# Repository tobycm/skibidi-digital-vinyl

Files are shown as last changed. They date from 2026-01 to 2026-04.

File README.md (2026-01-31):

# skibidi-digital-vinyl

a really cool vinyl emulator with digital tech

## Idea

Discs are made out of CH32V003 mcu, BY25Q32 flash, acts as a storage for audio file. Powered through pogo pins when placed in the player.

The player is powered with a RP2040 mcu, PTC PT8211-S DAC, and PAM8403 amplifier. USB powered, maybe battery powered in the future.

Maybe add a spinning motor in the future for extra effect.

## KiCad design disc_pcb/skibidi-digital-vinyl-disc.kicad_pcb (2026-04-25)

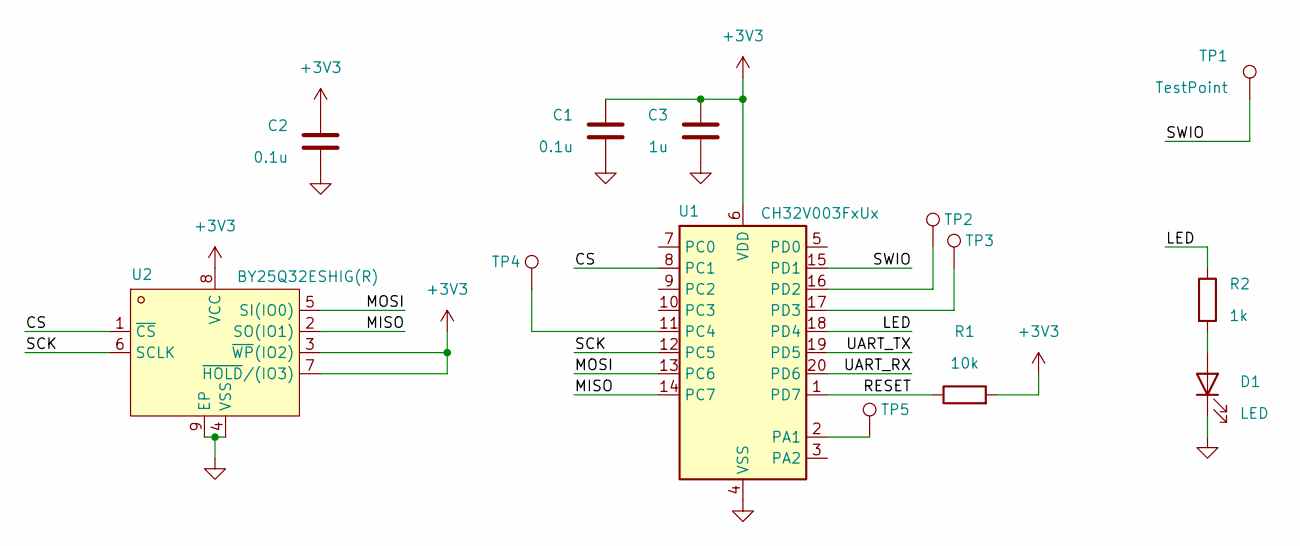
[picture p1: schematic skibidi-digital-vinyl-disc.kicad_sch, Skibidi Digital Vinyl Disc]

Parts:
C1, C2: 0.1u; C_0402_1005Metric; LCSC Part # C1525
C3: 1u; C_0402_1005Metric; LCSC Part # C52923
D1: LED; LED_0603_1608Metric; LCSC Part # C22371297
R1: 10k; R_0603_1608Metric; LCSC Part # C25804
R2: 1k; R_0603_1608Metric; LCSC Part # C21190
TP1, TP2, TP3, TP4, TP5: TestPoint; TestPoint_Pad_D1.0mm
U1: CH32V003FxUx; QFN-20-1EP_3x3mm_P0.4mm_EP1.65x1.65mm
U2: BY25Q32ESHIG(R); DFN-8_L4.0-W3.0-P0.80-TL-EP_GT5YL24A1Y520; LCSC Part C50176326

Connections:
+3V3: C1.1, C2.1, C3.1, R1.2, U1.6 (VDD), U2.3 (~WP(IO2)), U2.7 (~HOLD/(IO3)), U2.8 (VCC)
/CS: U1.8 (PC1), U2.1 (~CS)
/LED: R2.1, U1.18 (PD4)
/MISO: U1.14 (PC7), U2.2 (SO(IO1))
/MOSI: U1.13 (PC6), U2.5 (SI(IO0))
/RESET: R1.1, U1.1 (PD7)
/SCK: U1.12 (PC5), U2.6 (SCLK)
/SWIO: TP1.1, U1.15 (PD1); also elsewhere on the board
/UART_RX: U1.20 (PD6)
/UART_TX: U1.19 (PD5)
GND: C1.2, C2.2, C3.2, D1.1 (K), U1.4 (VSS), U1.21 (VSS), U2.4 (VSS), U2.9 (EP), U2.10 (EP)
unnamed: D1.2 (A), R2.2
unnamed: TP5.1, U1.2 (PA1)
unnamed: TP4.1, U1.11 (PC4)
unnamed: TP2.1, U1.16 (PD2)
unnamed: TP3.1, U1.17 (PD3)

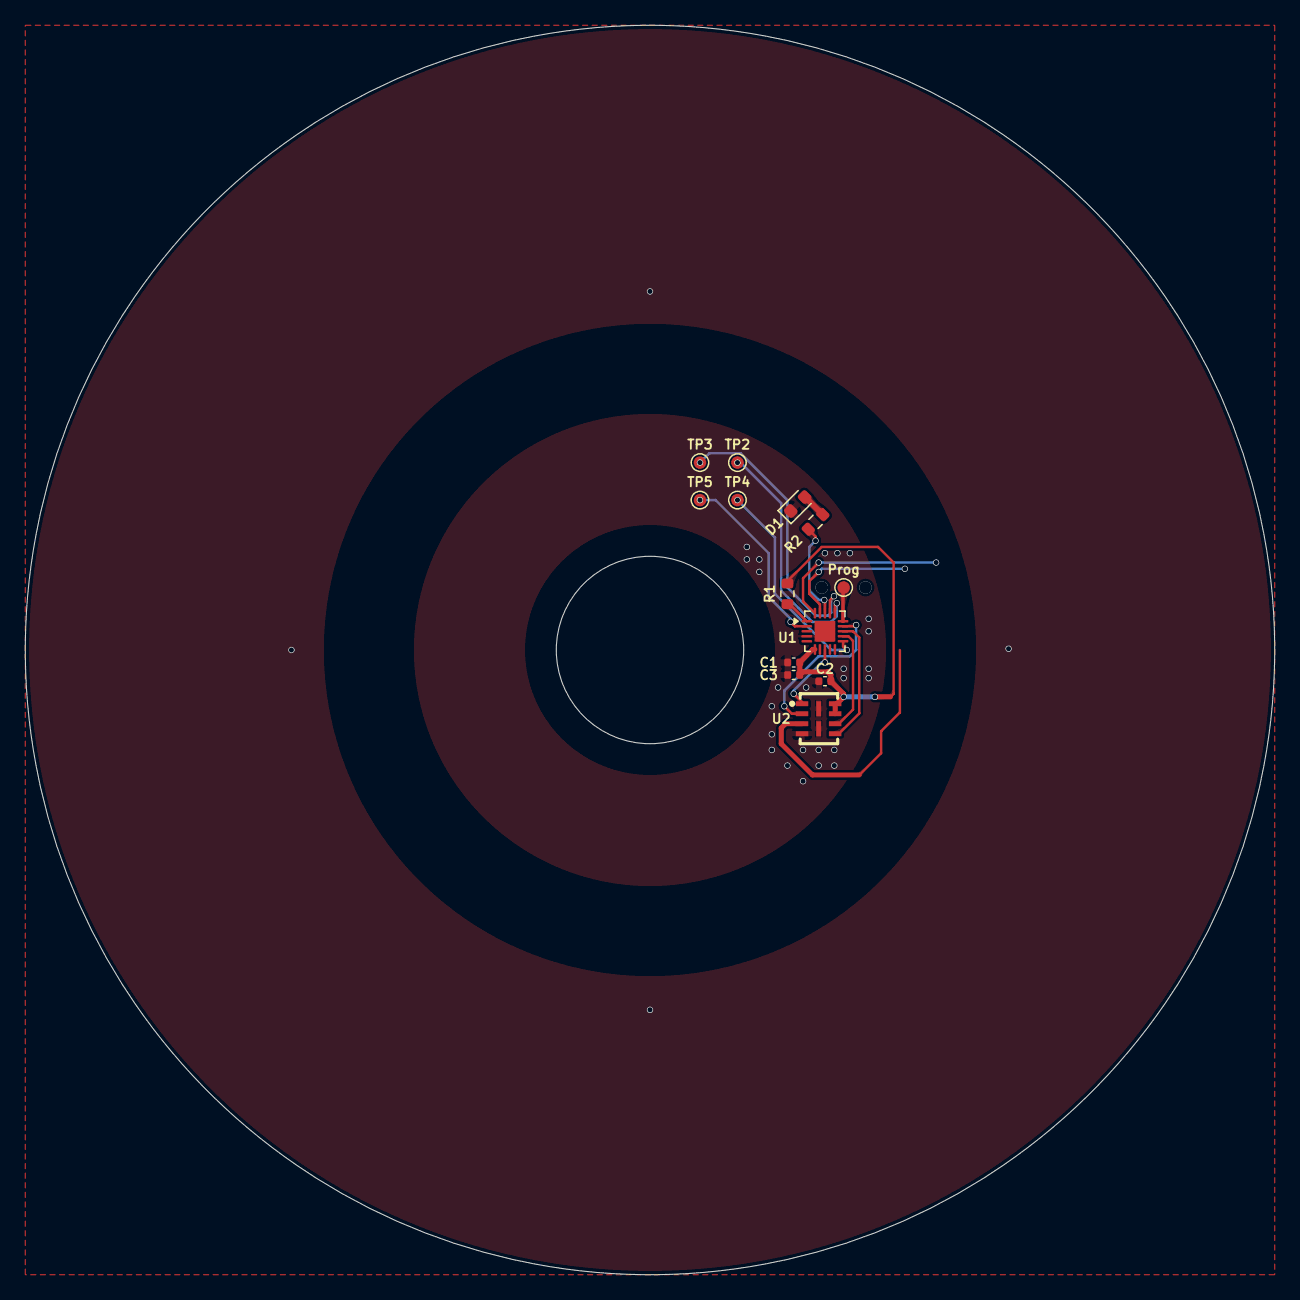
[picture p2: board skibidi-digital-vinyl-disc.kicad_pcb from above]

Board: 2 copper layers, 100.0 x 100.0 mm, 13 parts (0 on the bottom side), 14 nets.

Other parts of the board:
Prog: TestPoint; TestPoint_Pad_D1.0mm

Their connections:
/SWIO: Prog.1; also elsewhere on the board

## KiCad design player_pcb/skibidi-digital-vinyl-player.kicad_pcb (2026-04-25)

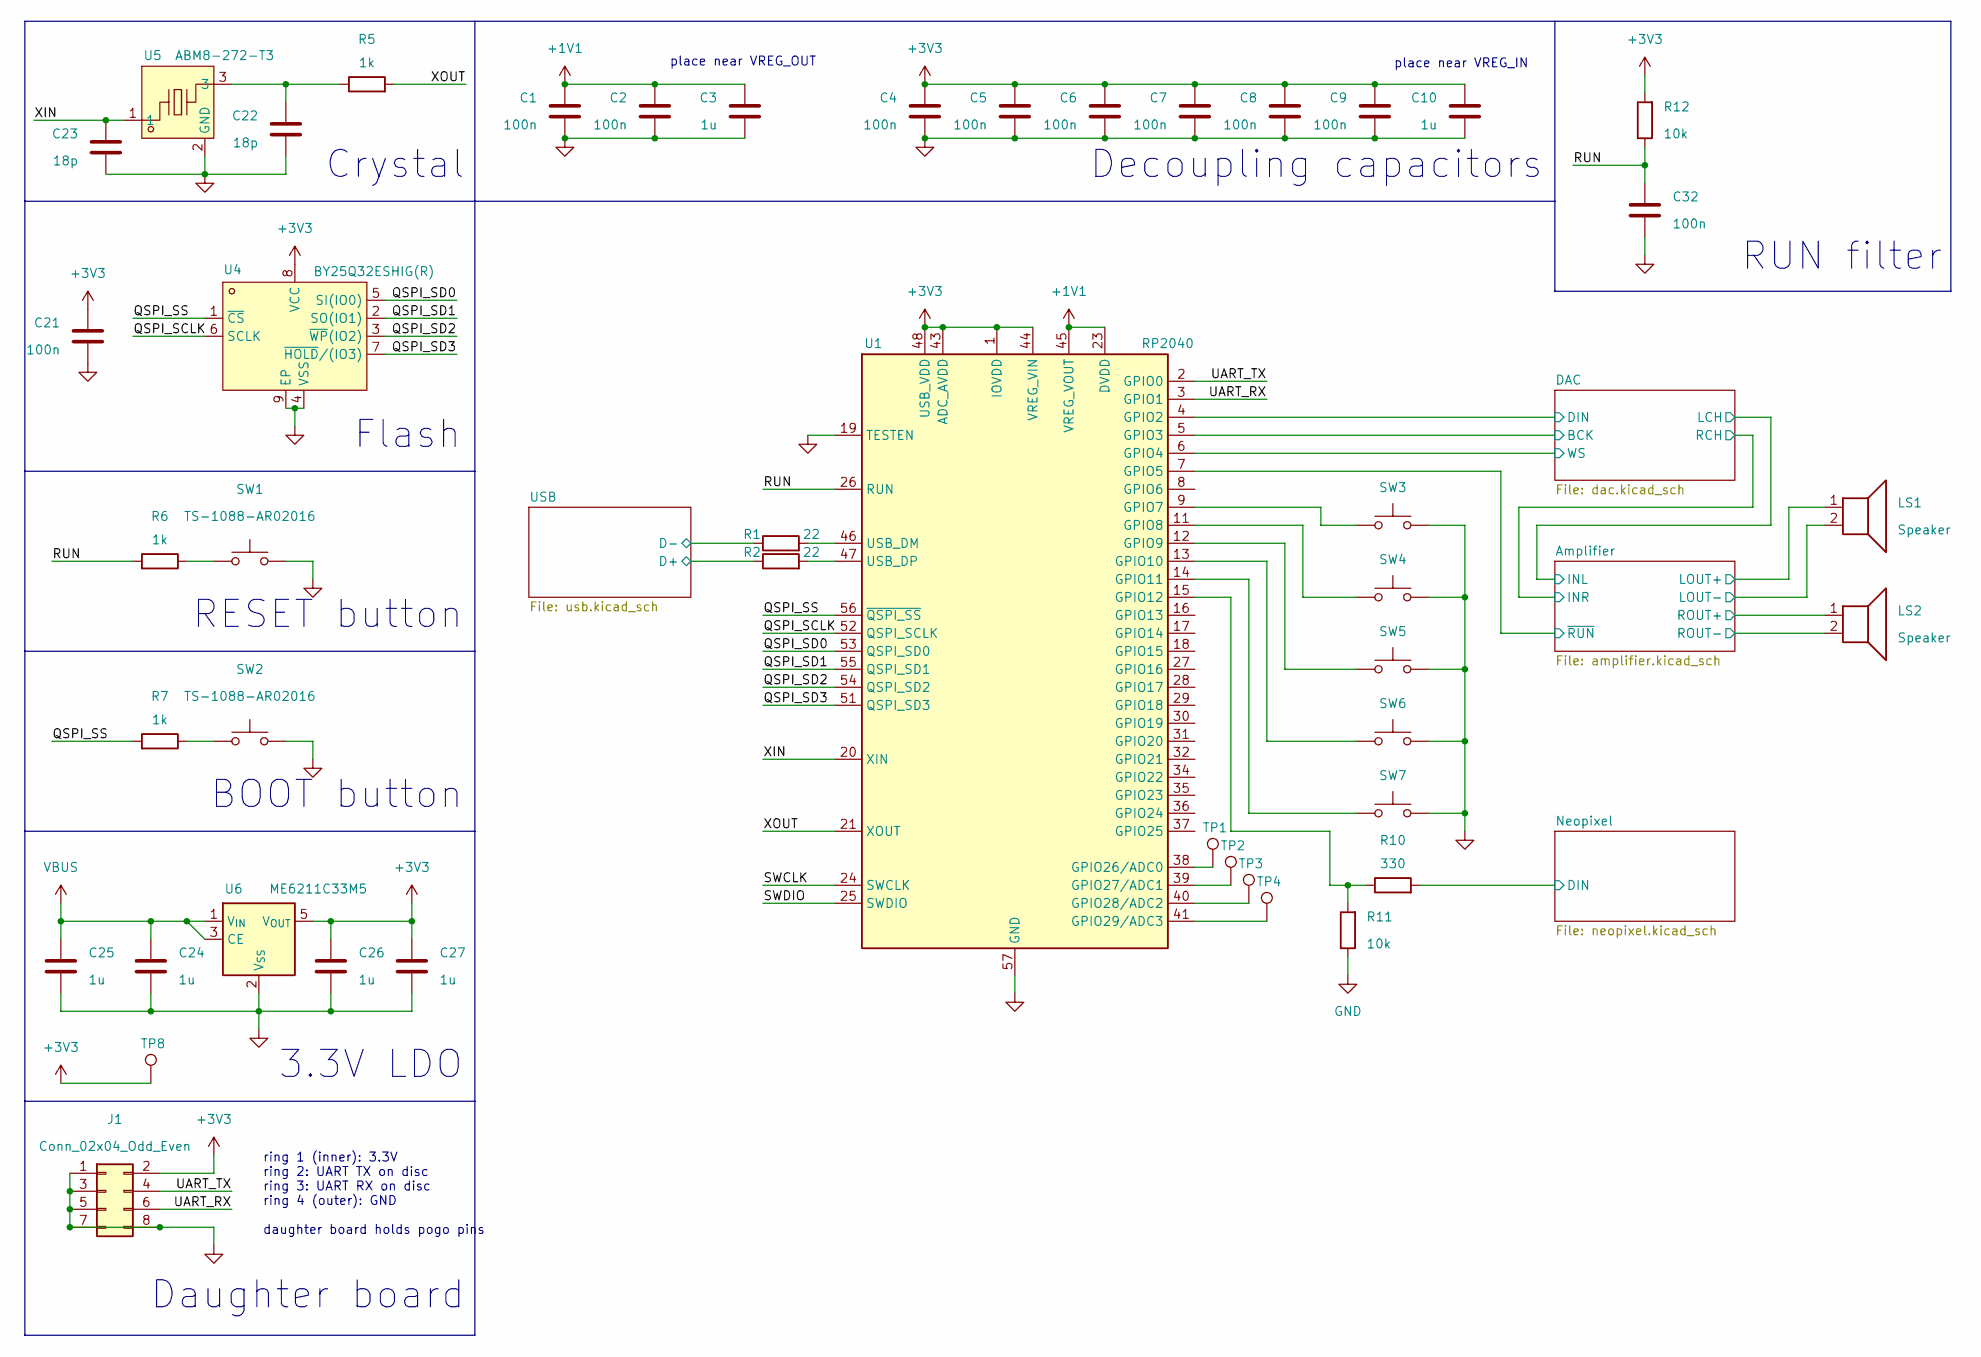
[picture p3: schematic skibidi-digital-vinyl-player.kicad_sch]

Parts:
C1, C2, C4, C5, C6, C7, C8, C9, C21, C32: 100n; C_0402_1005Metric; LCSC Part # C1525
C3, C10, C24, C25, C26, C27: 1u; C_0402_1005Metric; LCSC Part # C52923
C22, C23: 18p; C_0402_1005Metric; LCSC Part # C1549
J1: Conn_02x04_Odd_Even; JST_XH_S8B-XH-A_1x08_P2.50mm_Horizontal
LS1, LS2: Speaker; PinSocket_1x02_P2.54mm_Vertical
R1, R2: 22; R_0402_1005Metric; LCSC Part # C25092
R5, R6, R7: 1k; R_0603_1608Metric; LCSC Part # C21190
R10: 330; R_0603_1608Metric; LCSC Part # C23138
R11, R12: 10k; R_0603_1608Metric; LCSC Part # C25804
SW1, SW2: TS-1088-AR02016; SW_SPST_TS-1088-xR020; LCSC Part # C720477
SW3, SW4, SW5, SW6, SW7: SW_Push; SW_MX_1u
TP1, TP2, TP3, TP4, TP8: TestPoint; TestPoint_Pad_D1.0mm
U1: RP2040; QFN-56-1EP_7x7mm_P0.4mm_EP3.2x3.2mm; LCSC Part # C2040
U4: BY25Q32ESHIG(R); DFN-8_L4.0-W3.0-P0.80-TL-EP_GT5YL24A1Y520; LCSC Part C50176326
U5: ABM8-272-T3; CRYSTAL-SMD_4P-L3.2-W2.5-BL; LCSC Part C20625731
U6: ME6211C33M5; SOT-23-5

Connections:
+1V1: C1.1, C2.1, C3.1, U1.23 (DVDD), U1.45 (VREG_VOUT), U1.50 (DVDD)
+3V3: C4.1, C5.1, C6.1, C7.1, C8.1, C9.1, C10.1, C21.1, C26.1, C27.1, J1.2, R12.2, TP8.1, U1.1 (IOVDD), U1.10 (IOVDD), U1.22 (IOVDD), U1.33 (IOVDD), U1.42 (IOVDD), U1.43 (ADC_AVDD), U1.44 (VREG_VIN), U1.48 (USB_VDD), U1.49 (IOVDD), U4.8 (VCC), U6.5 (V_{OUT})
/Amplifier/LOUT+: LS1.1; also elsewhere on the board
/Amplifier/LOUT-: LS1.2; also elsewhere on the board
/Amplifier/ROUT+: LS2.1; also elsewhere on the board
/Amplifier/ROUT-: LS2.2; also elsewhere on the board
/Amplifier/~RUN: U1.7 (GPIO5); also elsewhere on the board
/DAC/BCK: U1.5 (GPIO3); also elsewhere on the board
/DAC/DIN: U1.4 (GPIO2); also elsewhere on the board
/DAC/WS: U1.6 (GPIO4); also elsewhere on the board
/Neopixel/DIN: R10.2; also elsewhere on the board
/QSPI_SCLK: U1.52 (QSPI_SCLK), U4.6 (SCLK)
/QSPI_SD0: U1.53 (QSPI_SD0), U4.5 (SI(IO0))
/QSPI_SD1: U1.55 (QSPI_SD1), U4.2 (SO(IO1))
/QSPI_SD2: U1.54 (QSPI_SD2), U4.3 (~WP(IO2))
/QSPI_SD3: U1.51 (QSPI_SD3), U4.7 (~HOLD/(IO3))
/RUN: C32.1, R6.2, R12.1, U1.26 (RUN)
/SWCLK: U1.24 (SWCLK)
/SWDIO: U1.25 (SWDIO)
/UART_RX: J1.6, U1.3 (GPIO1)
/UART_TX: J1.4, U1.2 (GPIO0)
/USB/D+: R2.1; also elsewhere on the board
/USB/D-: R1.1; also elsewhere on the board
/XIN: C23.1, U1.20 (XIN), U5.1
/XOUT: R5.2, U1.21 (XOUT)
unnamed: C22.1, R5.1, U5.3
unnamed: R6.1, SW1.2
unnamed: SW3.1, U1.9 (GPIO7)
unnamed: SW4.1, U1.11 (GPIO8)
unnamed: SW5.1, U1.12 (GPIO9)
unnamed: SW6.1, U1.13 (GPIO10)
unnamed: SW7.1, U1.14 (GPIO11)
unnamed: R10.1, R11.2, U1.15 (GPIO12)
unnamed: TP1.1, U1.38 (GPIO26/ADC0)
unnamed: TP2.1, U1.39 (GPIO27/ADC1)
unnamed: TP3.1, U1.40 (GPIO28/ADC2)
unnamed: TP4.1, U1.41 (GPIO29/ADC3)
unnamed: R1.2, U1.46 (USB_DM)
unnamed: R2.2, U1.47 (USB_DP)
VBUS: C24.1, C25.1, U6.1 (V_{IN}), U6.3 (CE); also elsewhere on the board

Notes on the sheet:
ring 1 (inner): 3.3V ring 2: UART TX on disc ring 3: UART RX on disc ring 4 (outer): GND daughter board holds pogo pins
place near VREG_IN
Flash
BOOT button
3.3V LDO
RUN filter
RESET button
Decoupling capacitors
Daughter board
Crystal
place near VREG_OUT

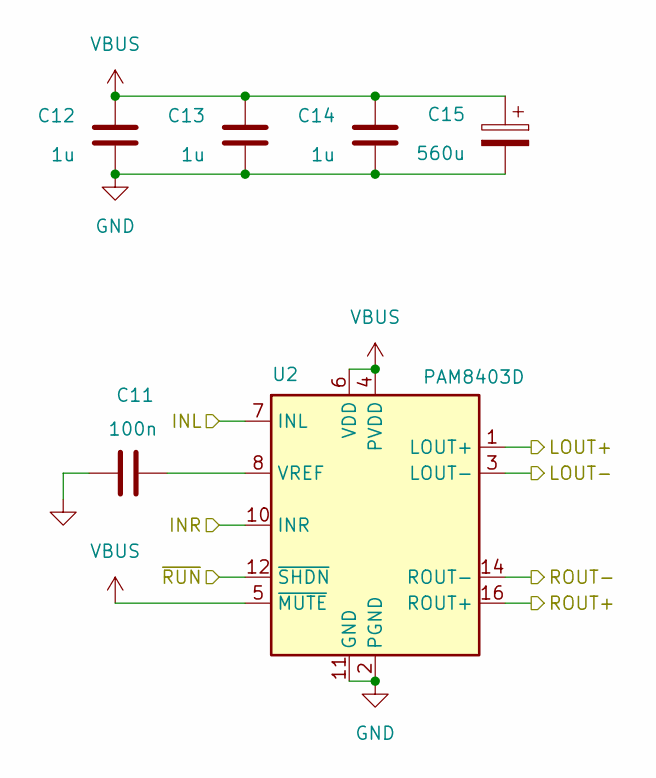
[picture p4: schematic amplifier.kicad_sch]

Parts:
C11: 100n; C_0402_1005Metric; LCSC Part # C1525
C12, C13, C14: 1u; C_0402_1005Metric; LCSC Part # C52923
C15: 560u; CP_Elec_10x10; LCSC Part # C19673857
U2: PAM8403D; SOIC-16_3.9x9.9mm_P1.27mm; LCSC Part # C53055751

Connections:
/Amplifier/INL: U2.7 (INL); also elsewhere on the board
/Amplifier/INR: U2.10 (INR); also elsewhere on the board
/Amplifier/LOUT+: U2.1 (LOUT+); also elsewhere on the board
/Amplifier/LOUT-: U2.3 (LOUT-); also elsewhere on the board
/Amplifier/ROUT+: U2.16 (ROUT+); also elsewhere on the board
/Amplifier/ROUT-: U2.14 (ROUT-); also elsewhere on the board
/Amplifier/~RUN: U2.12 (~SHDN); also elsewhere on the board
unnamed: C11.1, U2.8 (VREF)
VBUS: C12.1, C13.1, C14.1, C15.1, U2.4 (PVDD), U2.5 (~MUTE), U2.6 (VDD), U2.13 (PVDD); also elsewhere on the board

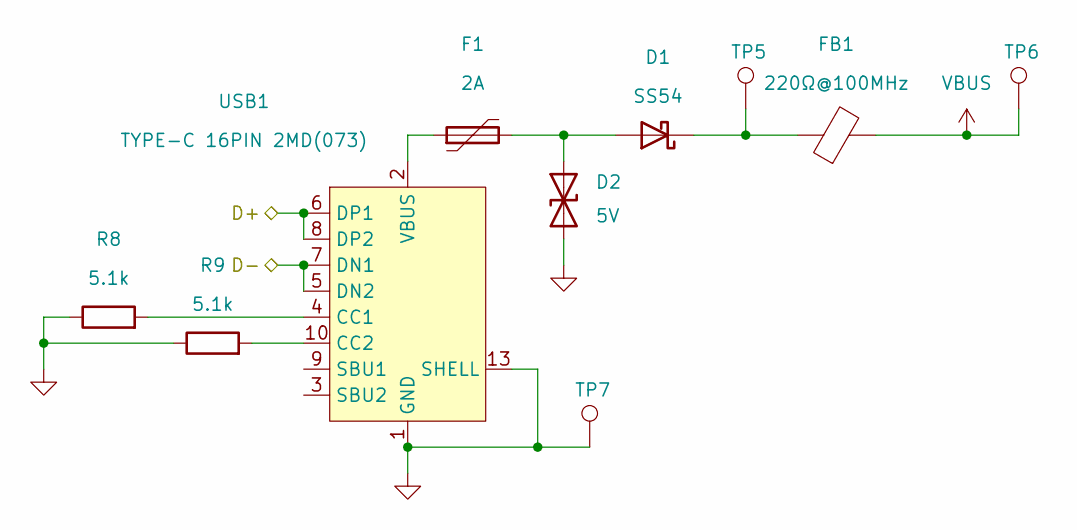
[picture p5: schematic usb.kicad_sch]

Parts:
D1: SS54; D_SMA; LCSC Part # C22452
D2: 5V; D_SOD-523; LCSC Part # C82044
F1: 2A; Fuse_1206_3216Metric; LCSC Part # C883135
FB1: 220Ω@100MHz; R_0805_2012Metric_Pad1.20x1.40mm_HandSolder; LCSC Part # C85840
R8, R9: 5.1k; R_0603_1608Metric; LCSC Part # C23186
TP5, TP6, TP7: TestPoint; TestPoint_Pad_D1.0mm
USB1: TYPE-C 16PIN 2MD(073); USB-C-SMD_TYPE-C-6PIN-2MD-073; LCSC Part C2765186

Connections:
/USB/D+: USB1.6 (DP1), USB1.8 (DP2); also elsewhere on the board
/USB/D-: USB1.5 (DN2), USB1.7 (DN1); also elsewhere on the board
unnamed: D1.2 (A), D2.1 (A1), F1.2
unnamed: D1.1 (K), FB1.1, TP5.1
unnamed: F1.1, USB1.2 (VBUS), USB1.11 (VBUS)
unnamed: R8.2, USB1.4 (CC1)
unnamed: R9.2, USB1.10 (CC2)
VBUS: FB1.2, TP6.1; also elsewhere on the board

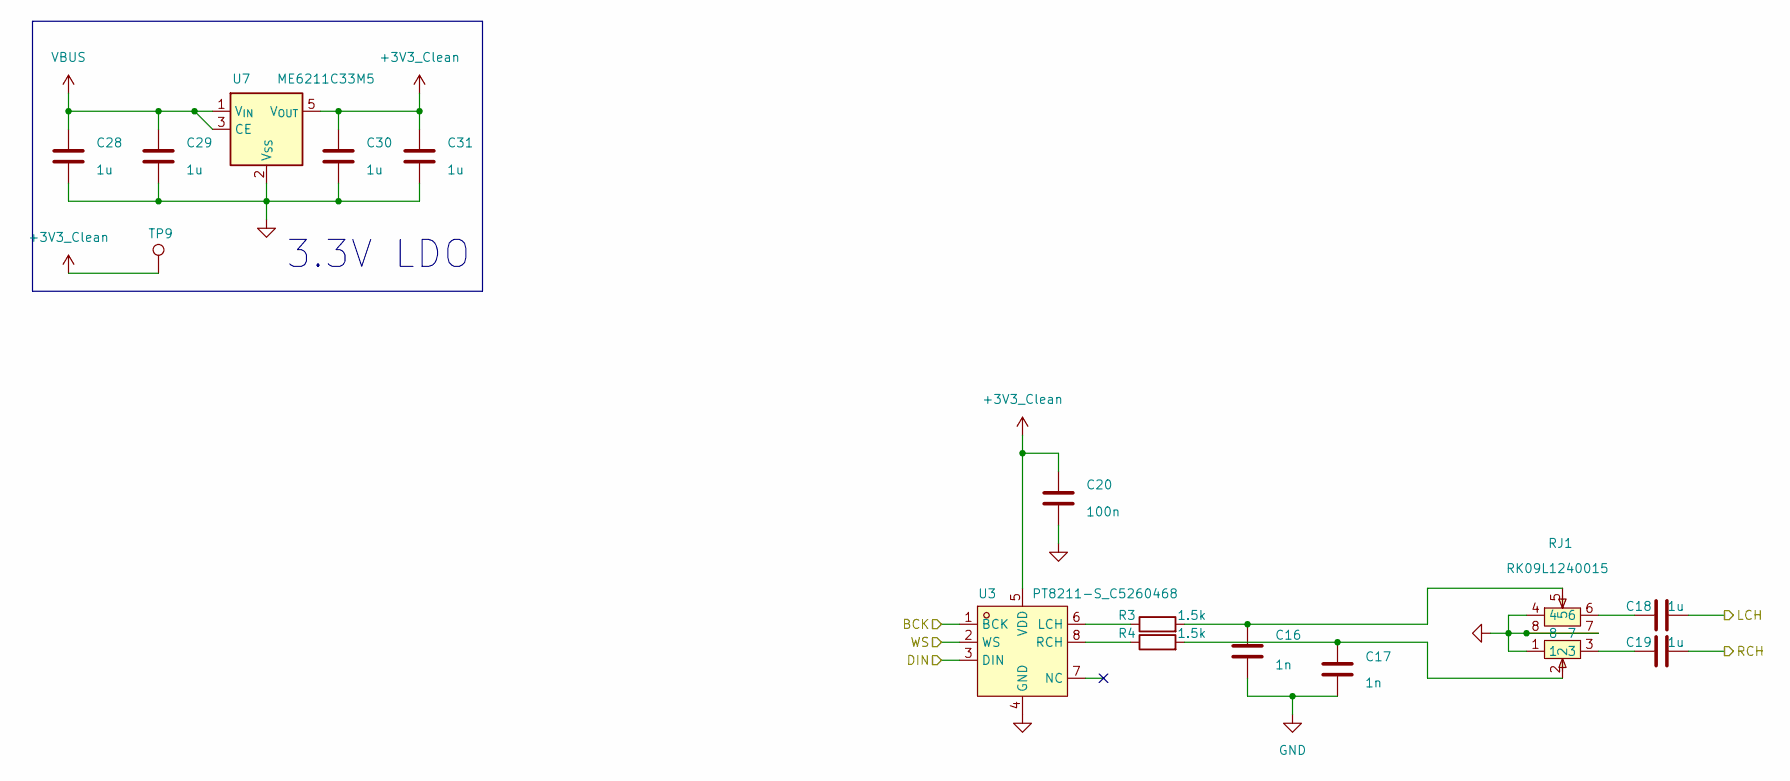
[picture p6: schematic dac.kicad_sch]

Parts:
C16, C17: 1n; C_0402_1005Metric; LCSC Part # C52923
C18, C19, C28, C29, C30, C31: 1u; C_0402_1005Metric; LCSC Part # C52923
C20: 100n; C_0402_1005Metric; LCSC Part # C1525
R3, R4: 1.5k; R_0402_1005Metric; LCSC Part # C25867
RJ1: RK09L1240015; RES-ADJ-TH_RK09L1240A12; LCSC Part C7471751
TP9: TestPoint; TestPoint_Pad_D1.0mm
U3: PT8211-S_C5260468; SOIC-8_L4.9-W3.9-P1.27-LS6.0-BL; LCSC Part C5260468
U7: ME6211C33M5; SOT-23-5

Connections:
+3V3_Clean: C20.1, C30.1, C31.1, TP9.1, U3.5 (VDD), U7.5 (V_{OUT})
/Amplifier/INL: C18.2; also elsewhere on the board
/Amplifier/INR: C19.2; also elsewhere on the board
/DAC/BCK: U3.1 (BCK); also elsewhere on the board
/DAC/DIN: U3.3 (DIN); also elsewhere on the board
/DAC/WS: U3.2 (WS); also elsewhere on the board
unnamed: C16.2, R3.2, RJ1.5
unnamed: C17.2, R4.2, RJ1.2
unnamed: C18.1, RJ1.6
unnamed: C19.1, RJ1.3
unnamed: R3.1, U3.6 (LCH)
unnamed: R4.1, U3.8 (RCH)
VBUS: C28.1, C29.1, U7.1 (V_{IN}), U7.3 (CE); also elsewhere on the board

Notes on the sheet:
3.3V LDO

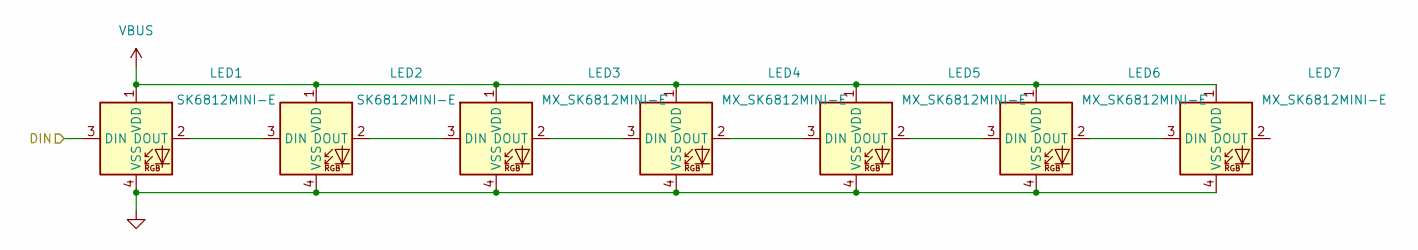
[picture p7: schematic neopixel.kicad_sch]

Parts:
LED1, LED2: SK6812MINI-E; LED_6028R
LED3, LED4, LED5, LED6, LED7: MX_SK6812MINI-E; LED_MX_6028R

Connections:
/Neopixel/DIN: LED1.3 (DIN); also elsewhere on the board
unnamed: LED1.2 (DOUT), LED2.3 (DIN)
unnamed: LED2.2 (DOUT), LED3.3 (DIN)
unnamed: LED3.2 (DOUT), LED4.3 (DIN)
unnamed: LED4.2 (DOUT), LED5.3 (DIN)
unnamed: LED5.2 (DOUT), LED6.3 (DIN)
unnamed: LED6.2 (DOUT), LED7.3 (DIN)
VBUS: LED1.1 (VDD), LED2.1 (VDD), LED3.1 (VDD), LED4.1 (VDD), LED5.1 (VDD), LED6.1 (VDD), LED7.1 (VDD); also elsewhere on the board

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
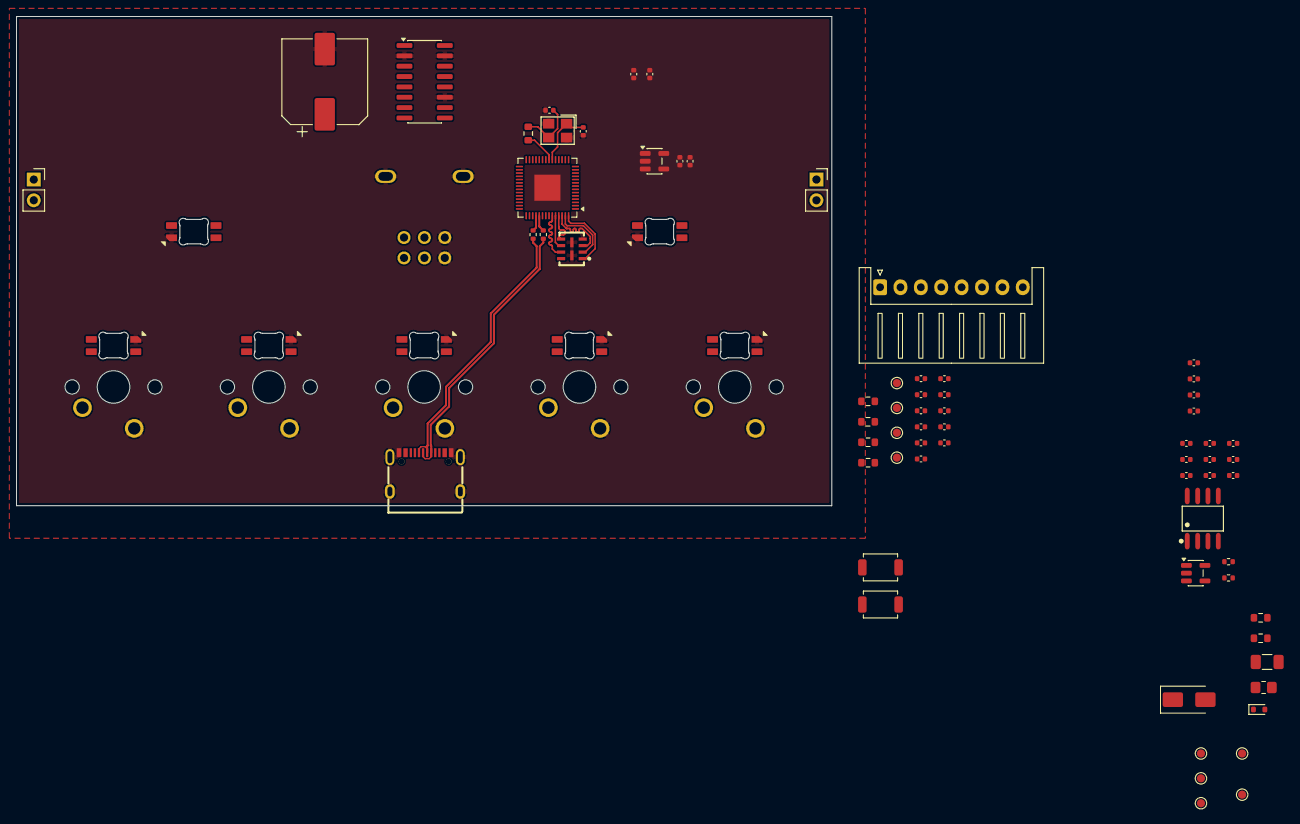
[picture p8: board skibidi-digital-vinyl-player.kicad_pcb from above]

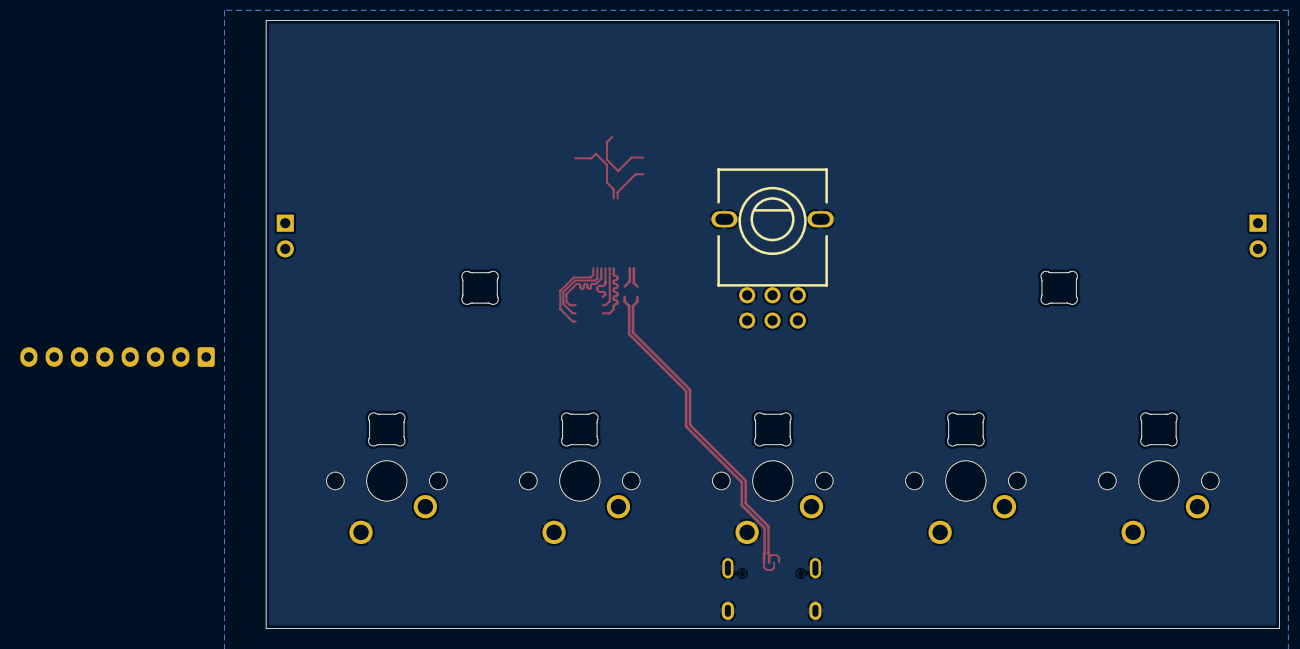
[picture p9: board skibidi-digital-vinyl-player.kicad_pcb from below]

Board: 2 copper layers, 100.0 x 60.0 mm, 81 parts (6 on the bottom side), 62 nets.

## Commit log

2026-01-31 general parts researched
    [skibidi-digital-vinyl.kicad_pcb, skibidi-digital-vinyl.kicad_sch]
2026-02-01 finished disc schematic, might add testpoints later to make full use of the ch32v003
    [skibidi-digital-vinyl.kicad_pcb, skibidi-digital-vinyl.kicad_sch]
2026-02-01 disc routing done
    [skibidi-digital-vinyl.kicad_pcb, skibidi-digital-vinyl.kicad_sch]
2026-02-01 update silkscreen text
    [skibidi-digital-vinyl.kicad_pcb, skibidi-digital-vinyl.kicad_sch]
2026-02-01 move to different folder
    [skibidi-digital-vinyl.kicad_pcb, skibidi-digital-vinyl.kicad_sch]
2026-02-01 most wiring done, only intracommunication with different modules wiring left
    [amplifier.kicad_sch, dac.kicad_sch, skibidi-digital-vinyl-disc.kicad_pcb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]
2026-02-01 second to done
    [skibidi-digital-vinyl-player.kicad_sch, usb.kicad_sch]
